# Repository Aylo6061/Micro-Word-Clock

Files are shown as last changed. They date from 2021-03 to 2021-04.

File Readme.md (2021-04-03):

# Micro Word Clock Kicad Edition!

## Description
Updated version of the micro word clock, laid out in Kicad for your viewing/editing pleasure.  This uses the commonly avalible adafruit matrix and has a battery backup for the RTC and a USB power jack.  This way it can be programmed once and whenever it is plugged in it should have the right time.

Per original description:

A tiny replica of the famous Word Clock, using only an ATmega microcontroller, a DS1307 Real Time Clock and a few passive components to display the time on an 8x8 LED matrix. The letters have been printed onto a transparent sheet and glued over the LEDs to produce a readable time.
See the YouTube video [here](https://www.youtube.com/watch?v=9ko9CeylUTs).

## Directory structure
- **MicroWordClock2-Arduino** contains the firmware, including pin definitions for the LED matrix and location of the words in each language.
- **KiCad** contains the schematic and PCB design files for the proeject.
- **Graphics** contains the design for the transparency sheet to place over the LED matrix to form the words, designed in Inkscape. Contributions in more languages are welcome!

## Bill of Materials

| | Part name | Package size | [Digikey](www.digikey.com) part number |
|---|---|---|---|
| U1 | ATmega328P-AU | TQFP-32 | ATMEGA328P-AURCT-ND |
| U3 | DS1307Z+ | SO-8 | DS1307Z+-ND |
| C1 | 1uF cap | 2012 metric / 0805 imperial  | 1276-6471-1-ND |
| C2 | 1uF cap | 2012 metric / 0805 imperial  | 1276-6471-1-ND |
| SW1 | SMD push button | "nanoT" aka VERY small | 108-NANOT240BSCT-ND |
| Y1 | 32.768 kHz crystal | 3216 metric / 1206 imperial  | 1908-1314-1-ND |
| LED matrix | 8x8 matrix | 20x20mm | [8x8 adafruit](https://www.adafruit.com/product/454https://www.adafruit.com/product/454)  |
| J1 | USB connector | smd connector | 609-4613-1-ND|
|BT1 | 3v lithium battery | thru hole tabs|	P192-ND | 
| PCB | | 20x20mm | [Order from osh park](https://oshpark.com/shared_projects/m8JDYR6z) 
## NB!!! Here be dragons!!! Warnings etc.

You will require an In-System Programmer (ISP) to write the firmware onto the microcontroller.

You will also need some way of attaching the ISP- I did not put nice pads on here for a standard atmel ISP header, instead these traces are routed to a board edge connector that I connected to with pogo pins. A standard .1" header stick could be soldered on for programming, or you could probably just push hard and get it to connect for a few seconds while you program.

The battery is not neccesary for this project to work- however if you do not have it, the clock will forget what time it is every time it is unplugged.

The button is VERY small.  If you dont like really trick surface mount soldering, you can omit it, but you wont be able to set the time.  If you have the battery mounted, this won't matter as the clock will remember what time it is (or if you experience DST or time zones changes).

## Burning the bootloader and uploading the sketch
Please download Carlos Rodrigues' Barebones ATmega Chips board configuration file:
https://github.com/carlosefr/atmega (instructions inside)

The ICSP header on the Micro Word Clock PCB is the silkscreened on the board.

## Contributions
Carl Monk has built [his own version](http://fortoffee.org.uk/2014/12/word-clock-with-a-unicorn/) using a [Unicorn HAT](http://shop.pimoroni.com/products/unicorn-hat).

[quistoph](https://github.com/qistoph) has made a Dutch layout.

Tanguy Rewers independently came up with an alternative Dutch layout (labeled as dutch2).

## License
This project (both software and hardware) is published under a [Creative Commons BY-SA 3.0 License](http://creativecommons.org/licenses/by-sa/3.0/).

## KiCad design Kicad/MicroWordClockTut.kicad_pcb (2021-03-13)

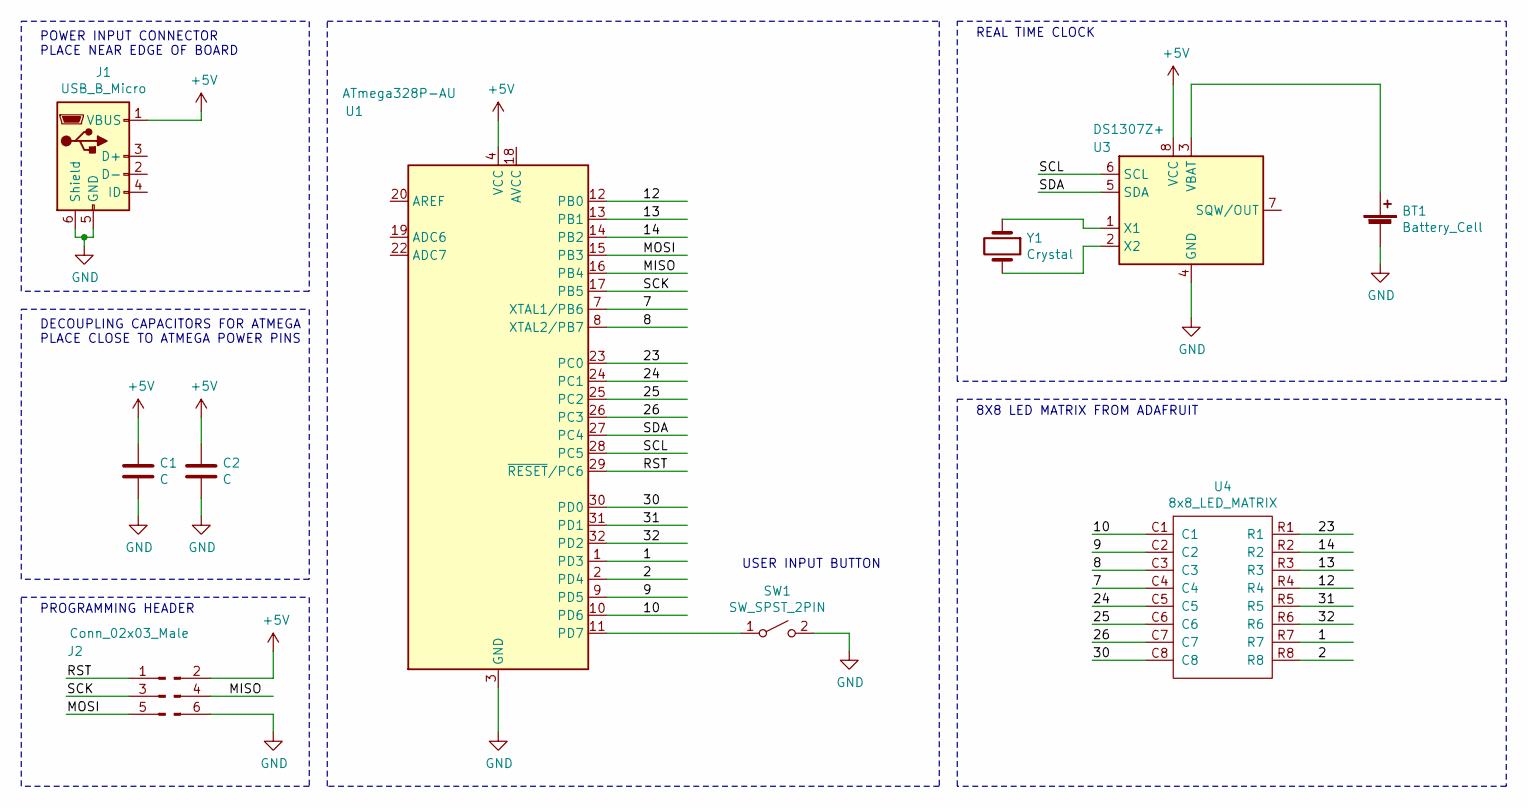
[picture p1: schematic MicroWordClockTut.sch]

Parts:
BT1: Battery_Cell; BR1225VCN
C1, C2: C; C_0805_HandSoldering
J1: USB_B_Micro; 10118192-0001LF
J2: Conn_02x03_Male; side connector
SW1: SW_SPST_2PIN; NanoT BS
U1: ATmega328P-AU; TQFP-32_7x7mm_Pitch0.8mm
U3: DS1307Z+; SOIC-8_3.9x4.9mm_Pitch1.27mm
U4: 8x8_LED_MATRIX; KWM-20882XVB
Y1: Crystal; 2-SMD XTAL CC7-T1A

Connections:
+5V: C1.1, C2.1, J1.1 (VBUS), J2.2, U1.4 (VCC), U1.6 (VCC), U3.8 (VCC)
/1: U1.1 (PD3), U4.R7
/2: U1.2 (PD4), U4.R8
/7: U1.7 (XTAL1/PB6), U4.C4
/8: U1.8 (XTAL2/PB7), U4.C3
/9: U1.9 (PD5), U4.C2
/10: U1.10 (PD6), U4.C1
/12: U1.12 (PB0), U4.R4
/13: U1.13 (PB1), U4.R3
/14: U1.14 (PB2), U4.R2
/23: U1.23 (PC0), U4.R1
/24: U1.24 (PC1), U4.C5
/25: U1.25 (PC2), U4.C6
/26: U1.26 (PC3), U4.C7
/30: U1.30 (PD0), U4.C8
/31: U1.31 (PD1), U4.R5
/32: U1.32 (PD2), U4.R6
/MISO: J2.4, U1.16 (PB4)
/MOSI: J2.5, U1.15 (PB3)
/RST: J2.1, U1.29 (~RESET~/PC6)
/SCK: J2.3, U1.17 (PB5)
/SCL: U1.28 (PC5), U3.6 (SCL)
/SDA: U1.27 (PC4), U3.5 (SDA)
GND: BT1.2 (-), C1.2, C2.2, J1.5 (GND), J1.6 (Shield), J2.6, SW1.2 (B), U1.3 (GND), U1.5 (GND), U1.21 (GND), U3.4 (GND)
unnamed: BT1.1 (+), U3.3 (VBAT)
unnamed: SW1.1 (A), U1.11 (PD7)
unnamed: U3.1 (X1), Y1.1
unnamed: U3.2 (X2), Y1.2

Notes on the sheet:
DECOUPLING CAPACITORS FOR ATMEGA PLACE CLOSE TO ATMEGA POWER PINS
POWER INPUT CONNECTOR PLACE NEAR EDGE OF BOARD
PROGRAMMING HEADER
USER INPUT BUTTON
REAL TIME CLOCK
8X8 LED MATRIX FROM ADAFRUIT

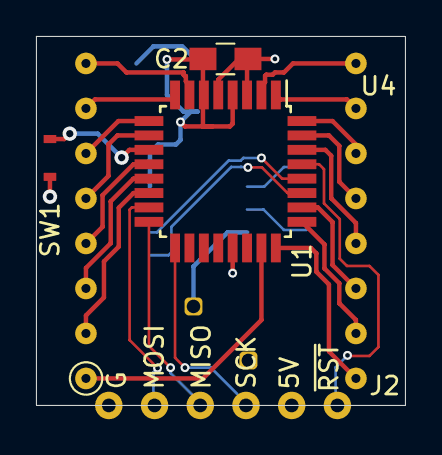
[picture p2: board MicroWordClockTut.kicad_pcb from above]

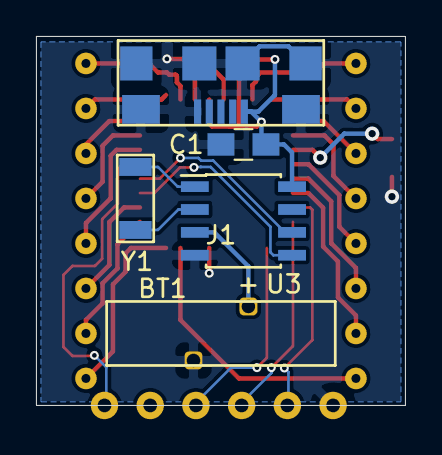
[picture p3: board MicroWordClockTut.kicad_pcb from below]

Board: 2 copper layers, 20.5 x 20.5 mm, 10 parts (5 on the bottom side), 28 nets.

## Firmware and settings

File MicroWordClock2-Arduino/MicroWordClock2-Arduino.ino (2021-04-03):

// Libraries
#include <Wire.h>
#include "RTClib.h"

// Local includes
#include "pindefs.h"
#include "otherdefs.h"

// Customizable options
#include "english.h" // exchange this for the language you need
boolean blink_enable = true;
boolean blinknow = false;
#define FREQ_DISPLAY 1000 // Hz
#define FREQ_TIMEUPDATE 2 // Hz
//unsigned long check_interval = 500; // time update rate
//#define refresh_rate 2560 // display refresh rate in microseconds

volatile int cols[]={ // PC0,PD4,PB6!,PB3,PD5,PB4,PC2,PC3
  MTX_COL1,MTX_COL2,MTX_COL3,MTX_COL4,MTX_COL5,MTX_COL6,MTX_COL7,MTX_COL8}; // ON=LOW
volatile int rows[]={ // PB2,PC1,PD7,PB5,PD2,PD6,PD3,PB7!
  MTX_ROW1,MTX_ROW2,MTX_ROW3,MTX_ROW4,MTX_ROW5,MTX_ROW6,MTX_ROW7,MTX_ROW8}; // ON=HIGH

enum ClockMode {
  NORMAL,
  SET_MIN,
  SET_HRS,
  END,
};
ClockMode clockmode = NORMAL;

volatile char disp[8]={
  0B11111111,
  0B11111111,
  0B11111111,
  0B11111111,
  0B11111111,
  0B11111111,
  0B11111111,
  0B11111111,
};

char testdisp[8]={
  0B11111111,
  0B00000011,
  0B00000101,
  0B00001001,
  0B00010001,
  0B00100001,
  0B01000001,
  0B10000001,
};

// RTC stuff
RTC_DS1307 rtc;
unsigned long disp_sec;
unsigned long disp_min;
unsigned long disp_hrs;

volatile boolean updatenow = false;

boolean buttonState = LOW;
unsigned long buttonMillis = 0;
boolean buttonHandled = true;

void loop() {
  if(updatenow) {
    updateTime();
    prepareDisplay();
    updatenow = false;
  }

  if(digitalRead(PIN_BUTTON) != buttonState) {
    buttonState = digitalRead(PIN_BUTTON);
    if(buttonState == LOW) { // button was pressed
      buttonMillis = millis();
      buttonHandled = false;
    }
    else { // button was released
      buttonHandled = true;
      unsigned long buttonDelay = millis() - buttonMillis;
      if(buttonDelay > 100) { // debounce
        if(buttonDelay < 1000) { // simple press
          updatenow = true;
          switch(clockmode) {
          case NORMAL:
            blink_enable = !blink_enable;
            blinknow = true;
            TCNT1 = 0;
            break;
          case SET_MIN:
            rtc.adjust(rtc.now().unixtime() + 1*60);
            blinknow = true;
            TCNT1 = 0;
            break;
          case SET_HRS:
            rtc.adjust(rtc.now().unixtime() + 1*60*60);
            blinknow = true;
            TCNT1 = 0;
            break;
          }
        }
      }
    }
  }
  else {
    if(buttonState == LOW && !buttonHandled) { // button is being pressed
      unsigned long buttonDelay = millis() - buttonMillis;
      if(buttonDelay > 2000) {
        blinknow = false;
        TCNT1 = 0;
        clockmode = (ClockMode)((int)clockmode + 1);
        if(clockmode == END)
          clockmode = NORMAL;
        buttonHandled = true;
        updatenow = true;
      }
    }
  }
}

void updateTime() {
  // Adjust 2.5 minutes = 150 seconds forward
  // So at 12:03 it already reads "five past 12"
  DateTime now = rtc.now().unixtime() + 150;

  disp_sec = now.second();
  disp_min = now.minute();
  disp_hrs = now.hour();

  disp_min /= 5;

  if(disp_min >= min_offset)
    ++disp_hrs %= 12;
  else
    disp_hrs   %= 12;
}

void prepareDisplay() {
  blinknow = !blinknow;
  FOR_ALLROWS {
    disp[r]=B00000000;
    FOR_ALLCOLS {
      // disp[r]|=testdisp[r]; //uncomment this line to output test code
      if((clockmode != SET_MIN || !blinknow))
        disp[r] |= minutes[disp_min][r] & (B10000000 >> c);
      if((clockmode != SET_HRS || !blinknow))
        disp[r] |= hours  [disp_hrs][r] & (B10000000 >> c);
      if(clockmode == NORMAL && blink_enable && !blinknow)
        disp[r] |= blinky[r];
    }
  }
}

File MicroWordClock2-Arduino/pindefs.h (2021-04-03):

// Matching LED rows/columns to the matrix's pins
// to microcontroller ports to microcontroller pins
// to Arduino pin notation. Whew.

// PORTB: Digital pins (offset 8), PB6/PB7 are XTAL
// PORTC: Analog pins (no offset), PC6 is RESET, PC7 nonexistent
// PORTD: Digital pins (no offset)

// Pin definitions
#define PIN_BUTTON PD7

// Mapping Matrix Row/Col numbers to Matrix pins
#define MTX_ROW1 MTX_PIN4
#define MTX_ROW2 MTX_PIN3
#define MTX_ROW3 MTX_PIN2
#define MTX_ROW4 MTX_PIN1
#define MTX_ROW5 MTX_PIN9
#define MTX_ROW6 MTX_PIN10
#define MTX_ROW7 MTX_PIN11
#define MTX_ROW8 MTX_PIN12

#define MTX_COL1 MTX_PIN16
#define MTX_COL2 MTX_PIN15
#define MTX_COL3 MTX_PIN14
#define MTX_COL4 MTX_PIN13
#define MTX_COL5 MTX_PIN5
#define MTX_COL6 MTX_PIN6
#define MTX_COL7 MTX_PIN7
#define MTX_COL8 MTX_PIN8

#define MTX_PIN1  SIG_23
#define MTX_PIN2  SIG_14
#define MTX_PIN3  SIG_13
#define MTX_PIN4  SIG_12
#define MTX_PIN5  SIG_10
#define MTX_PIN6  SIG_9
#define MTX_PIN7  SIG_8
#define MTX_PIN8  SIG_7
#define MTX_PIN9  SIG_2
#define MTX_PIN10 SIG_1
#define MTX_PIN11 SIG_32
#define MTX_PIN12 SIG_31
#define MTX_PIN13 SIG_30
#define MTX_PIN14 SIG_26
#define MTX_PIN15 SIG_25
#define MTX_PIN16 SIG_24

#define SIG_24  PC1
#define SIG_23  PC0
#define SIG_14  PB2
#define SIG_13  PB1
#define SIG_9   PD5
#define SIG_12  PB0
#define SIG_10  PD6
#define SIG_8   PB7
#define SIG_25  PC2
#define SIG_26  PC3
#define SIG_30  PD0
#define SIG_31  PD1
#define SIG_32  PD2
#define SIG_1   PD3
#define SIG_2   PD4
#define SIG_7   PB6

#define PB0  8
#define PB1  9
#define PB2 10
#define PB3 11
#define PB4 12
#define PB5 13
#define PB6 A6 //XTAL1
#define PB7 A7 //XTAL2

#define PC0 A0
#define PC1 A1
#define PC2 A2
#define PC3 A3
#define PC4 A4
#define PC5 A5


#define PD0 0
#define PD1 1
#define PD2 2
#define PD3 3
#define PD4 4
#define PD5 5
#define PD6 6
#define PD7 7

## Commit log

2021-03-02 kicad version using the original matrix and a matrix from luckylight (bought at adafruit). errors are in this initial commit
    [MicroWordClockTut.kicad_pcb, MicroWordClockTut.sch]
2021-03-02 changed pindefs to reflect currently committed schematic
2021-03-03 started routing. it is small. pinswapped a lot
    [MicroWordClockTut.kicad_pcb, MicroWordClockTut.sch]
2021-03-06 latest version with tiny switch NanoT
    [MicroWordClockTut.kicad_pcb, MicroWordClockTut.sch]
2021-03-13 this version released to osh park
    [MicroWordClockTut.kicad_pcb]
2021-04-03 final version of pindefs for the kicad board
2021-04-03 edited readme to include link to pcb
